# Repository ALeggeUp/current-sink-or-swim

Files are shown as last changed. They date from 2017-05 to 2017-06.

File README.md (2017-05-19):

# Current Sink or Swim (CSOS)

Project work from The Online Electronics Aprenticeship program at [Contextual Electronics](https://contextualelectronics.com/)

# License

This work is licensed under the Creative Commons Attribution 4.0 International License. To view a copy of this license, visit http://creativecommons.org/licenses/by/4.0/ or send a letter to Creative Commons, PO Box 1866, Mountain View, CA 94042, USA.

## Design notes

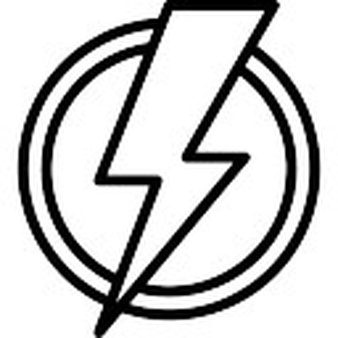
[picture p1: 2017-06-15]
design/images/current_318-137753.jpg

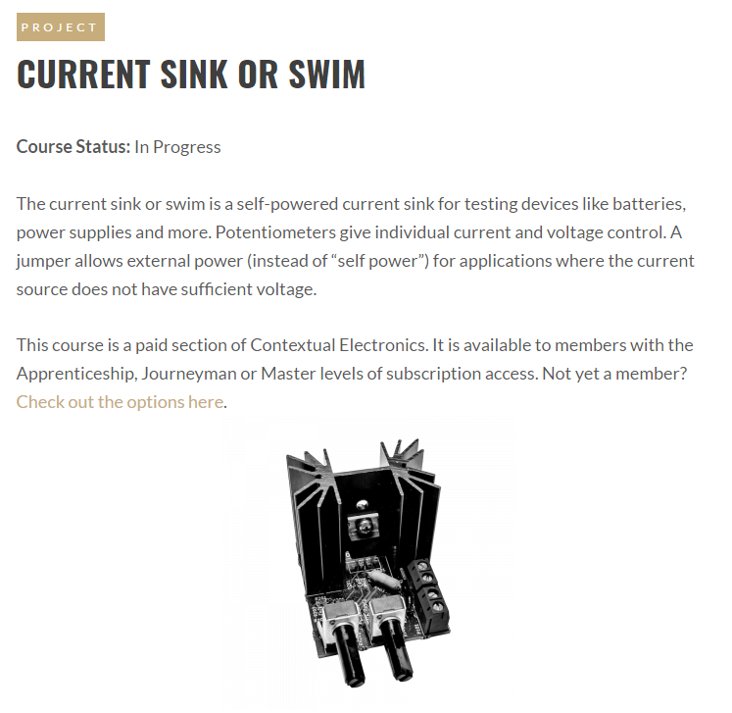
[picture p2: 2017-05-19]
design/images/project-initial-summary.png

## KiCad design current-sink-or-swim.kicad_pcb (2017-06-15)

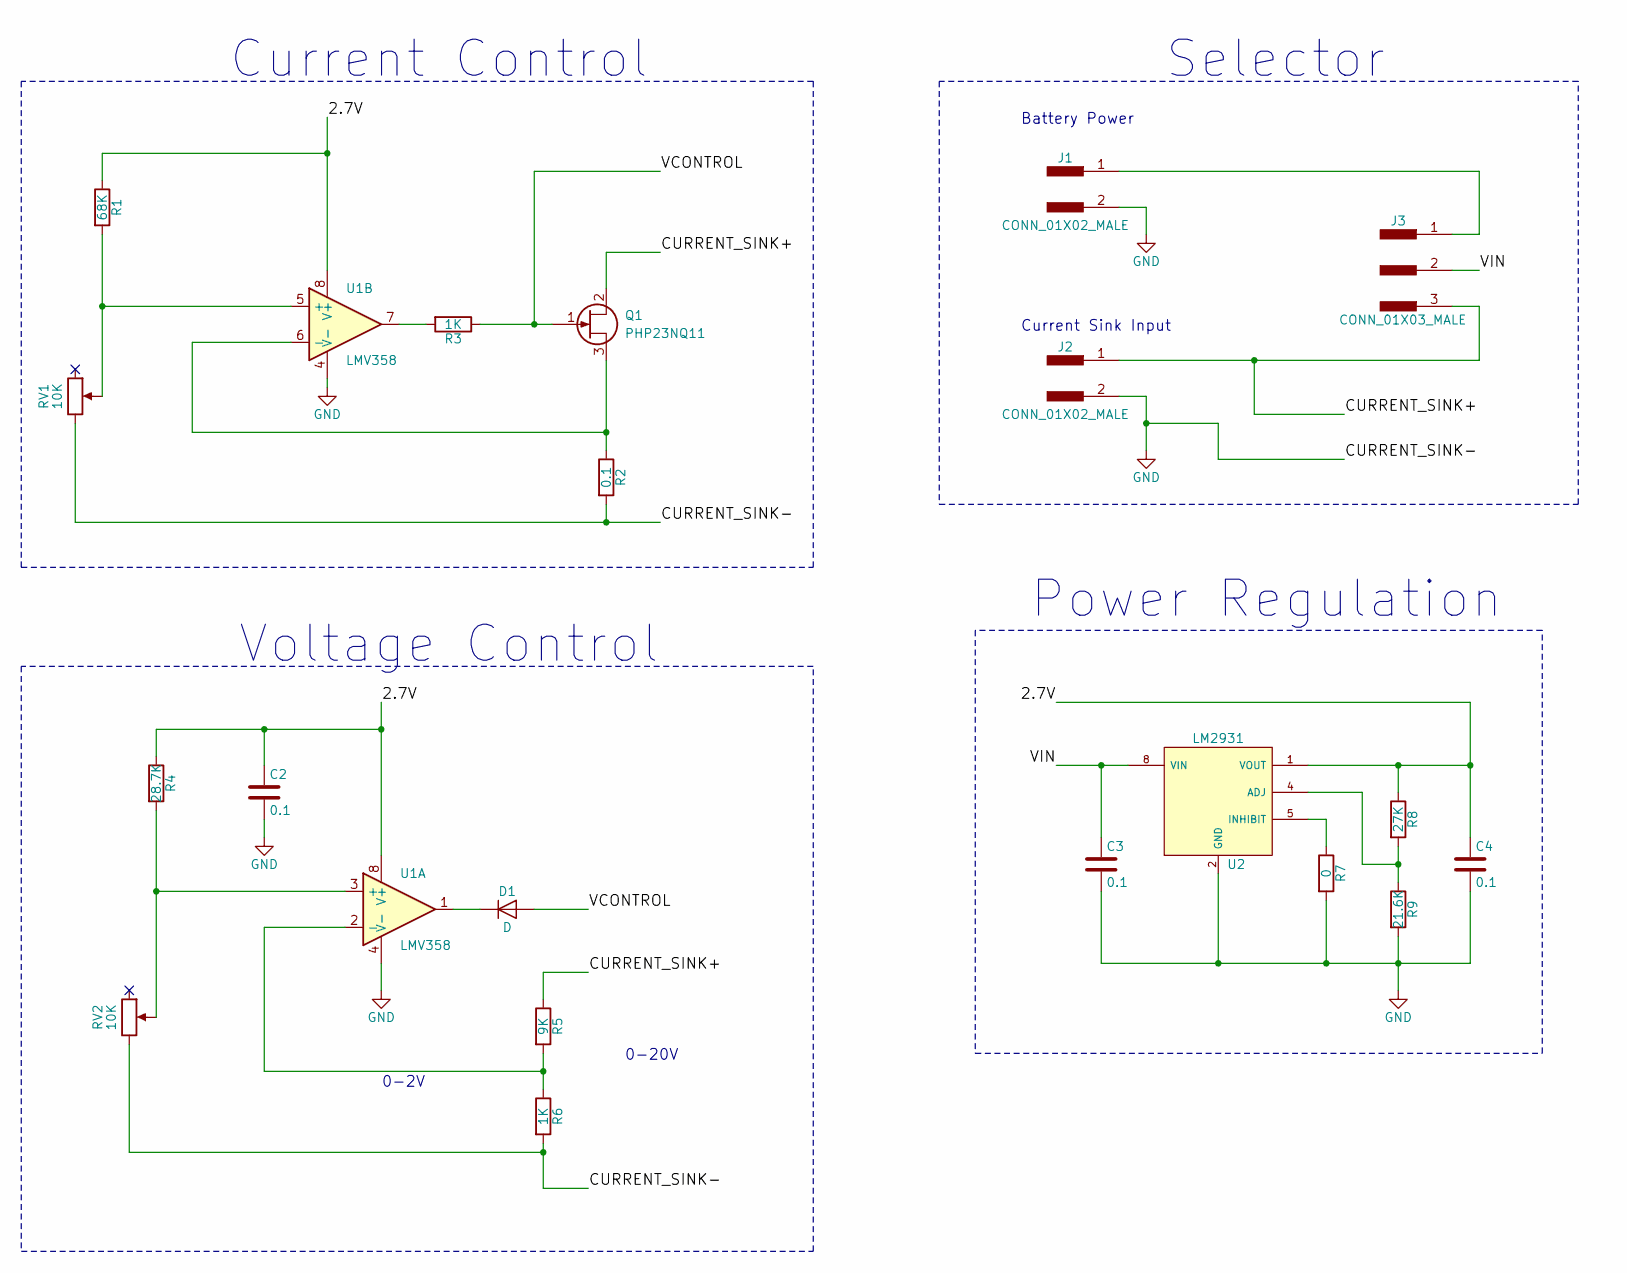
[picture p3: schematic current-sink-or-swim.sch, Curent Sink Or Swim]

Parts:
C2, C3, C4: 0.1; C_0805_HandSoldering
D1: D; D_SOD-123; MPN 1N4148W-TP
J1, J2: CONN_01X02_MALE; TerminalBlock_Pheonix_PT-5mm_2pol; MPN 1792863
J3: CONN_01X03_MALE; Pin_Header_Straight_1x03_Pitch2.54mm
Q1: PHP23NQ11; TO-220_Vertical; MPN PHP23NQ11T,127
R1: 68K; R_0805_HandSoldering; MPN RC0805JR-0768KL
R2: 0.1; R_Axial_DIN0414_L11.9mm_D4.5mm_P15.24mm_Horizontal; MPN AC01000001007JA100
R3, R6: 1K; R_0805_HandSoldering; MPN RC0805JR-071KL
R4: 28.7K; R_0805_HandSoldering; MPN RC0805FR-0728K7L
R5: 9K; R_0805_HandSoldering; MPN RC0805FR-079K09L
R7: 0; R_0805_HandSoldering; MPN RC0805JR-070RL
R8: 27K; R_0805_HandSoldering; MPN RC0805FR-0727KL
R9: 21.6K; R_0805_HandSoldering; MPN RC0805FR-0721K5L
RV1, RV2: 10K; P090L-02F25BR10K
U1: LMV358; SOIC-8_3.9x4.9mm_Pitch1.27mm
U2: LM2931; SOIC-8_3.9x4.9mm_Pitch1.27mm; MPN LM2931CDR2G

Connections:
/2.7V: C2.1, C4.1, R1.1, R4.1, R8.1, U1.8 (V+), U2.1 (VOUT); also elsewhere on the board
/CURRENT_SINK+: J2.1, J3.3, Q1.2 (D), R5.1
/VCONTROL: D1.2 (A), Q1.1 (G), R3.1
/VIN: C3.1, J3.2, U2.8 (VIN)
GND: C2.2, C3.2, C4.2, J1.2, J2.2, R2.2, R6.2, R7.2, R9.2, RV1.3, RV2.3, U1.4 (V-), U2.2 (GND), U2.3 (GND), U2.6 (GND), U2.7 (GND); also elsewhere on the board
unnamed: D1.1 (K), U1.1
unnamed: J1.1, J3.1
unnamed: Q1.3 (S), R2.1, U1.6 (-)
unnamed: R1.2, RV1.2, U1.5 (+)
unnamed: R3.2, U1.7
unnamed: R4.2, RV2.2, U1.3 (+)
unnamed: R5.2, R6.1, U1.2 (-)
unnamed: R7.1, U2.5 (INHIBIT)
unnamed: R8.2, R9.1, U2.4 (ADJ)

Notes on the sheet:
Current Sink Input
Battery Power
Power Regulation
Current Control
Voltage Control
Selector
0-20V
0-2V

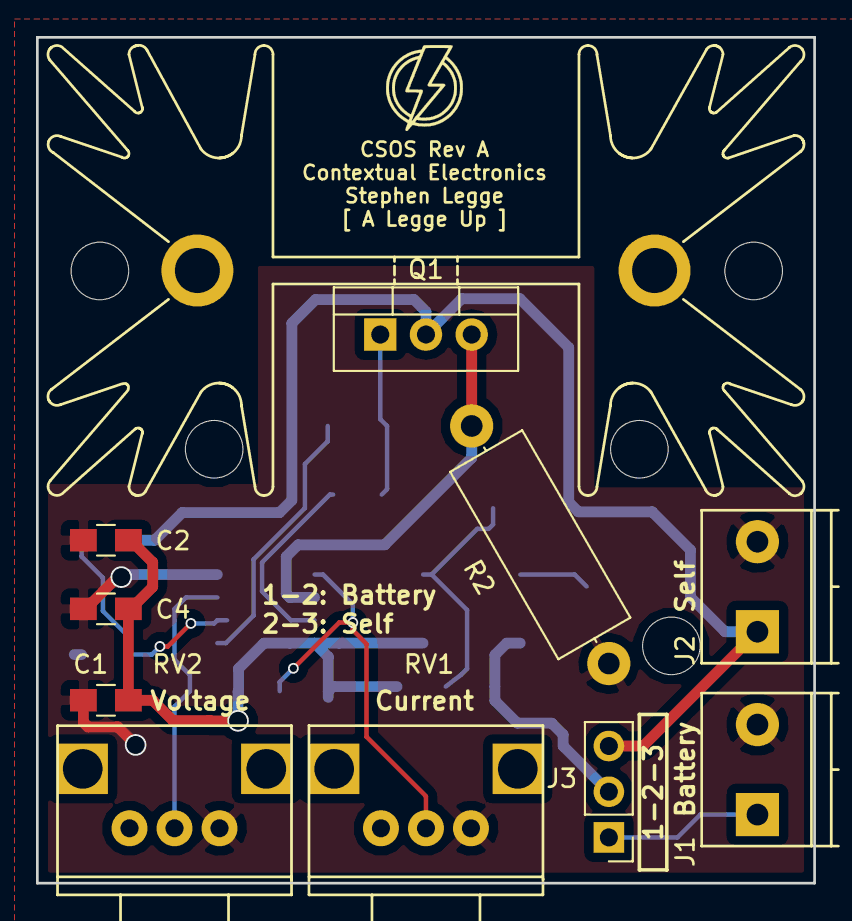
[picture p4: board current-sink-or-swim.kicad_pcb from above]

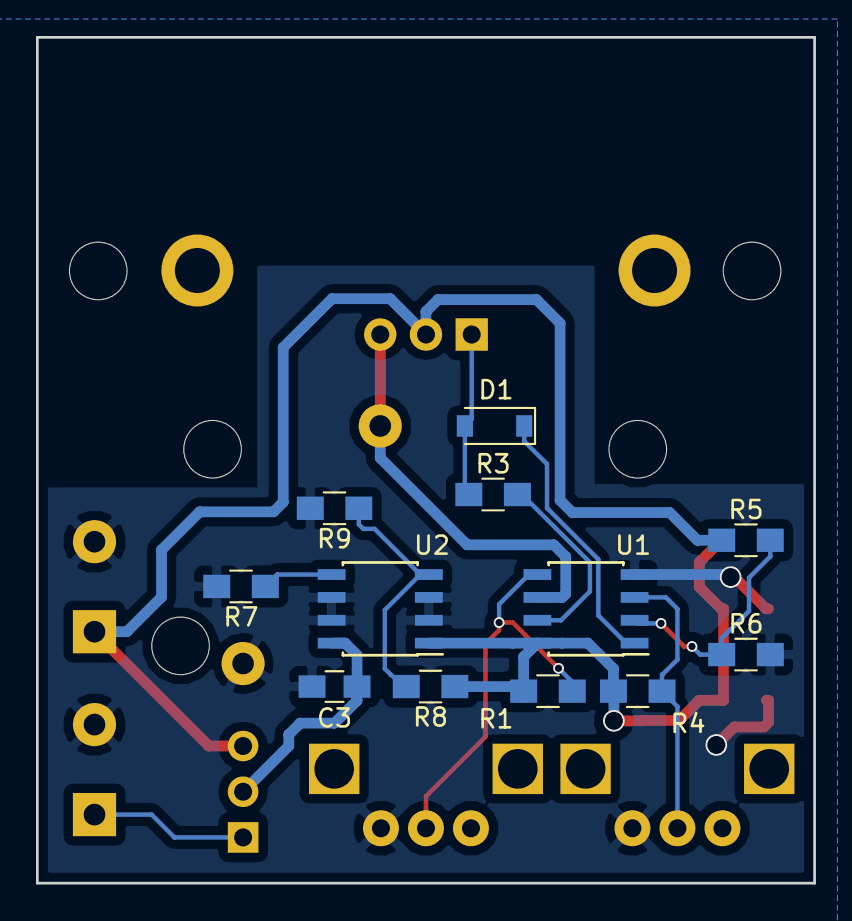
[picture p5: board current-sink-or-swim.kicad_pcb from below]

Board: 2 copper layers, 43.2 x 47.0 mm, 22 parts (12 on the bottom side), 14 nets.

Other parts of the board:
C1: C; C_0805_HandSoldering

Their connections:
/2.7V: C1.1; also elsewhere on the board
GND: C1.2; also elsewhere on the board

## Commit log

2017-05-19 Initial commit of the KiCad project files
    [current-sink-or-swim.kicad_pcb, current-sink-or-swim.sch]
2017-05-19 Symbols created for CSOS project (op-amp and voltage regulator)
2017-05-19 Insert new local libraries at the top of the list
2017-05-19 Schematic capture to match up with CSOS Project step
    "Creating the Initial CSOS Schematic" at CE
    [current-sink-or-swim.sch]
2017-05-19 Moved some things around and added some MPN's where known
    [current-sink-or-swim.sch]
2017-05-19 Add reference to datasheet for TC1016
    [current-sink-or-swim.sch]
2017-05-20 Added LM2931 linear regulator schematic symbol to local library
2017-05-20 Added voltage control and reorganized/cleaned up the page
    [current-sink-or-swim.sch]
2017-05-20 Annotated schematic automatically and then made some manual tweaks
    [current-sink-or-swim.sch]
2017-05-20 Changed background of IC schematic symbol to be filled to match the KLC
2017-05-20 Added metadata for components and links to datasheets
    [current-sink-or-swim.sch]
2017-05-22 Added heatsink and updated to correct FET symbol
    [current-sink-or-swim.sch]
2017-05-22 Datasheets for terminal blocks, heatsink and potentiometer
2017-06-15 Added part metadata to the schematic for BOM
    [current-sink-or-swim.sch]
2017-06-15 Removed pin that was standing in as heatsink
2017-06-15 Layout of board as ordered
    [current-sink-or-swim.kicad_pcb]
2017-06-15 Footprints created for CSOS
2017-06-15 Image used as "logo" on the board
